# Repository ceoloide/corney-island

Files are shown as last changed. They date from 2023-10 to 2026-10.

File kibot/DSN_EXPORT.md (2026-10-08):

# KiCad DSN export repair

`export_dsn.py` repairs KiCad's native DSN using the source PCB. Run it in
KiCad's Python environment; the source board is never saved or modified.

```sh
python3 kibot/export_dsn.py -b board.kicad_pcb -o board.dsn
```

From the repository root with KiCad 9 Docker:

```sh
docker run --rm -v "$PWD:/board" -w /board --entrypoint python3 \
  ghcr.io/inti-cmnb/kicad9_auto:latest kibot/export_dsn.py \
  -b pcbs/corney_island_wireless.kicad_pcb -o /board/wireless.dsn
```

## Precision

KiCad serializes some coordinates with six significant digits, losing source
precision on large or rotated boards. The repair restores wire vertices, via
centers, polygonized board boundaries, footprint placements, local pin positions,
and identified circular NPTH centers. Source matching uses KiCad's native
rounding and source identity/net/layer where applicable. Ambiguous matches fail
instead of selecting a nearby point. Shared library images are split when
different source geometry has identical rounded serialization.

The repair preserves widths, rules, nets, layers, rotations, and declared DSN
resolution. It does not snap contacts to Freerouting's internal grid. Native
padstack shapes and arbitrary custom-pad geometry retain their exported values.
Arc tracks are unsupported; export fails rather than attempting to match them.
The implementation currently requires micrometer DSN exports and was tested
with KiCad 9.0.7. Output replacement is atomic, preserving existing output on
failure.

## NPTH clearance

The exporter preserves KiCad's native NPTH obstacle extents. It restores source
coordinate precision without removing the clearance already included in those
obstacles. The experimental `normalize_npth` utility remains in
`dsn_precision.py` with unit coverage, but is not invoked by the exporter.
There is no `--keep-native-npth` switch: preservation is the default behavior.

Freerouting's circular obstacle approximation and coordinate rounding remain
separate issues. Check imported routes with unfiltered KiCad DRC; precision
repair alone does not establish complete or correct autorouting.

## Build integration

`build.sh` applies the two-layer JLCPCB profile with `configure_jlcpcb.py`
before export and writes unfiltered pre-route and post-route DRC reports to
`reports/routing/`. Existing `.kicad_dru` files survive generation and are left
unchanged; the helper creates custom rules only if that file is absent.

`routing_status.py` rejects missing connections or DRC errors for the specific
board. Failed boards skip final fabrication exports, and the batch continues
with subsequent boards and prints a failure summary. Board-level failures do
not set a nonzero batch exit status; generation failures still do.

## Validation

```sh
python3 -m unittest discover -s kibot/tests -v
```

Thirteen tests cover coordinate restoration, ambiguous matches, descriptor
preservation, shared-image splitting, NPTH identity and layer matching,
oversized extents, implicit circle origins, rule-area rejection, and idempotence.
Integration checks on both saved keyboard boards and a ten-angle fixture verify
source-PCB preservation, unchanged rules/resolution/nets, and idempotence of the
precision repair. The batch regression checks that DRC and routing failures
do not prevent later boards from building and that custom rules are retained.
Freerouting import testing does not establish complete autorouting or replace
post-routing KiCad DRC.

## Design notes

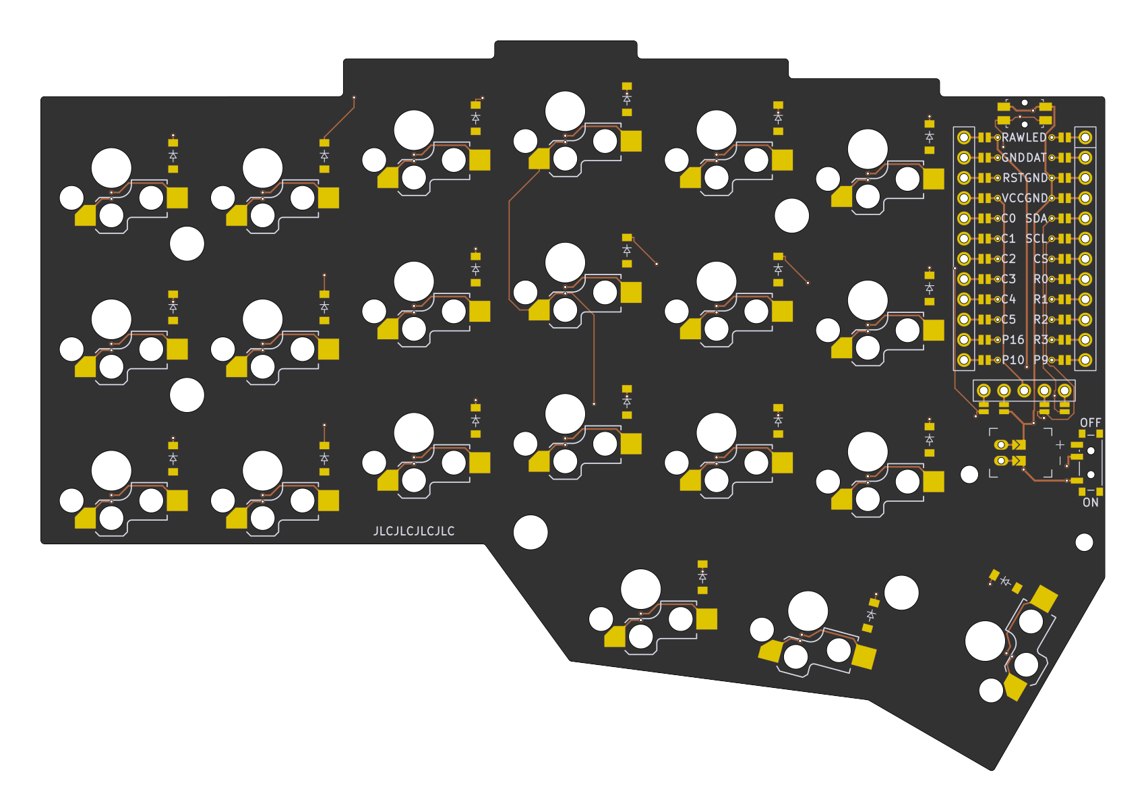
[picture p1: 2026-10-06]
images/corney_island_wireless_autorouted-top.png

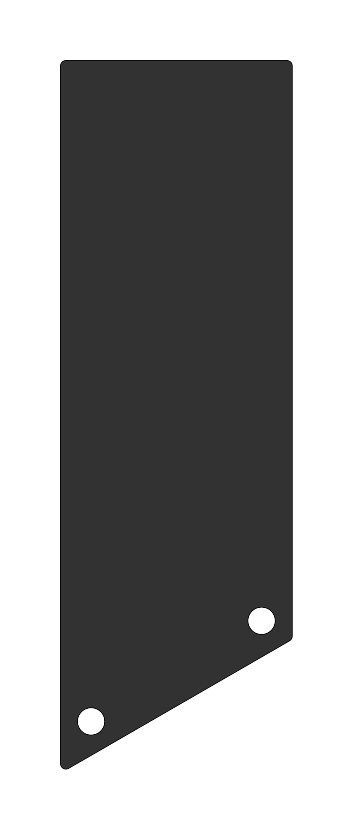
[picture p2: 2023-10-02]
images/controller_overlay-bottom.png

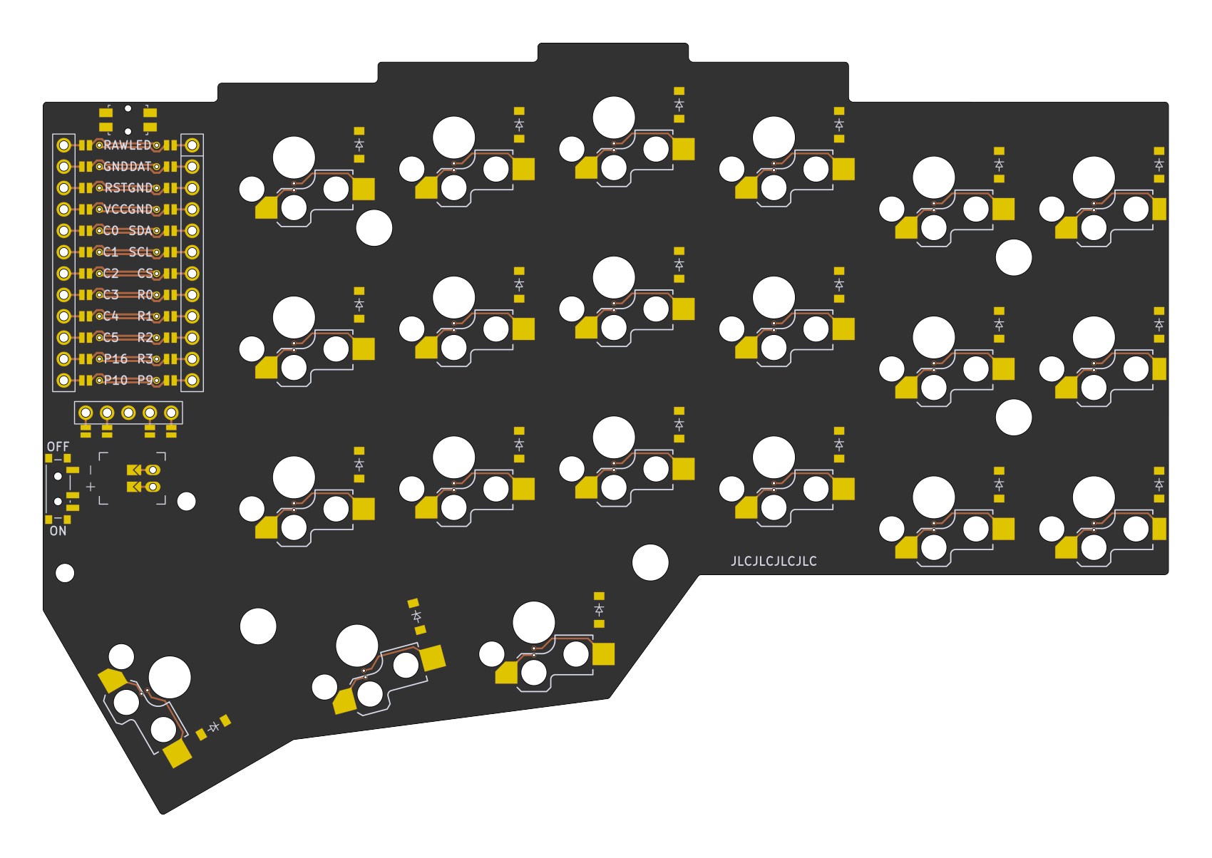
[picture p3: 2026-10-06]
images/corney_island_wireless-bottom.png

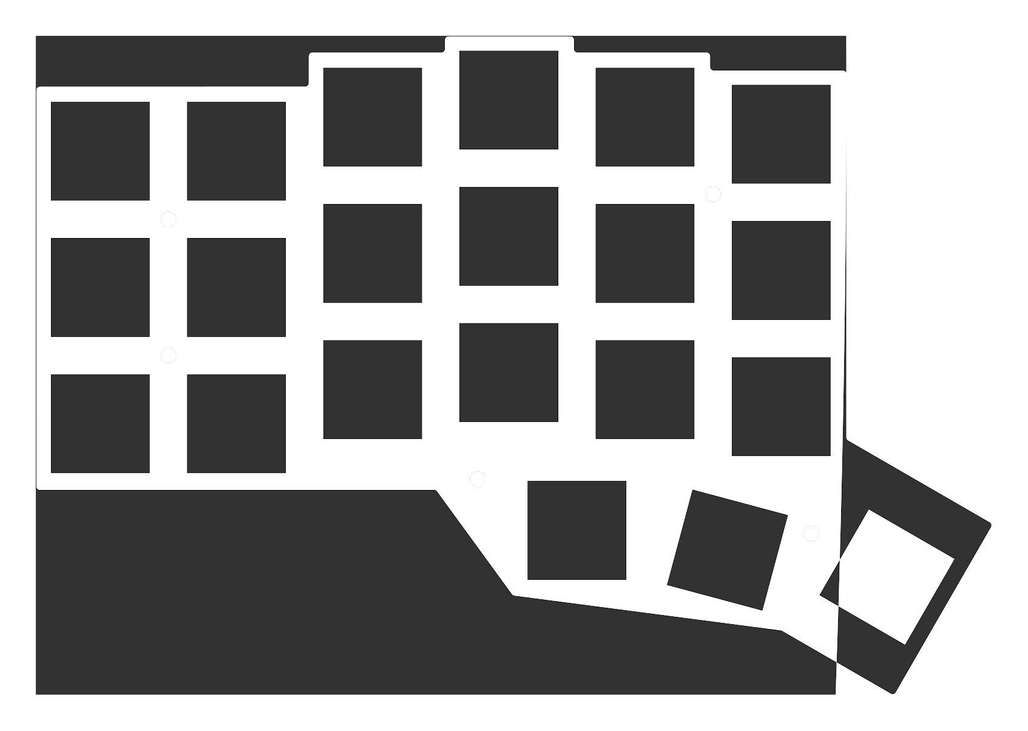
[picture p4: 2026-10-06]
images/frontplate-top.png

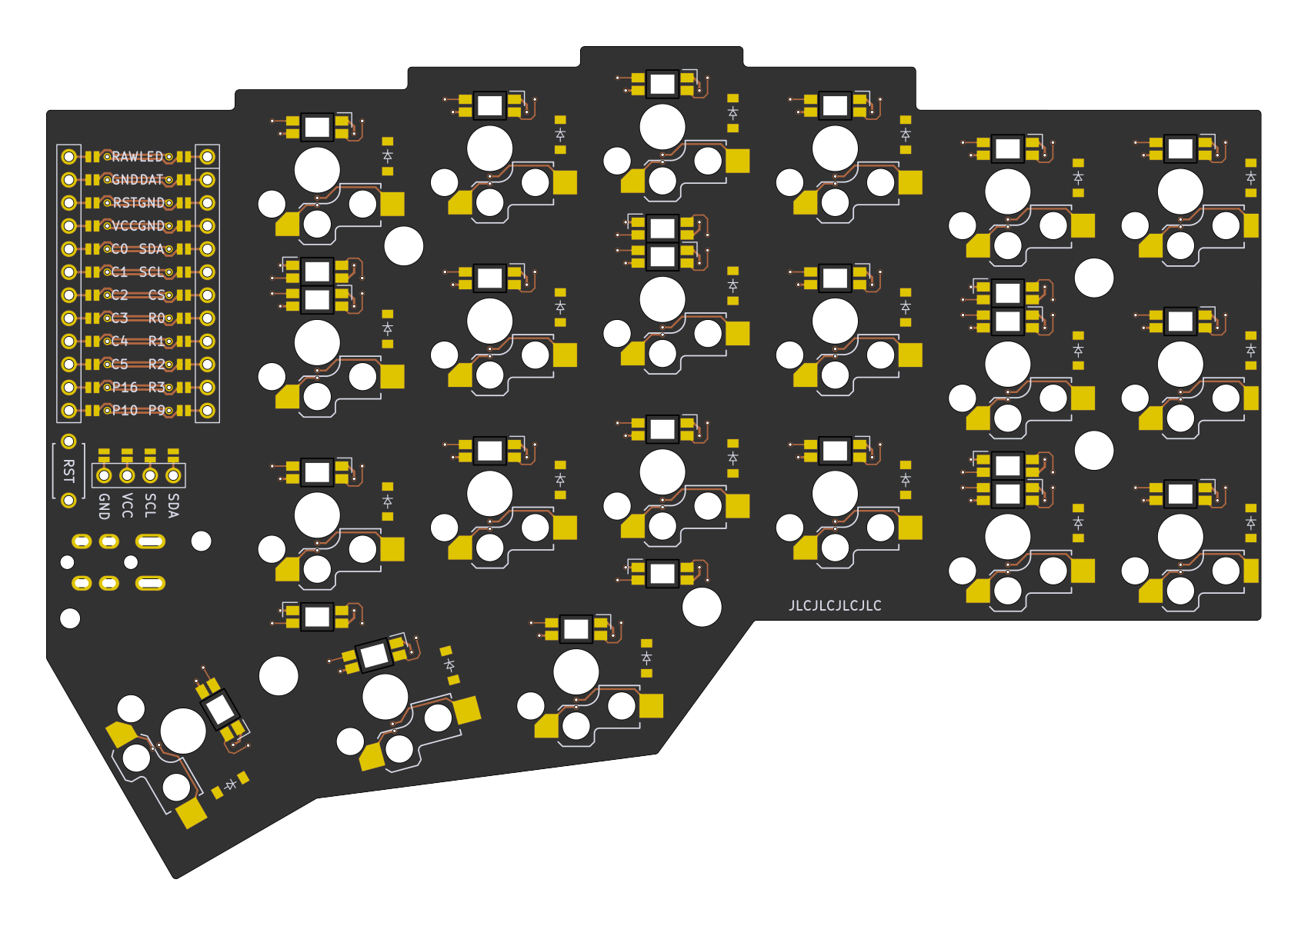
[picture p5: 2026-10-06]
images/corney_island-bottom.png

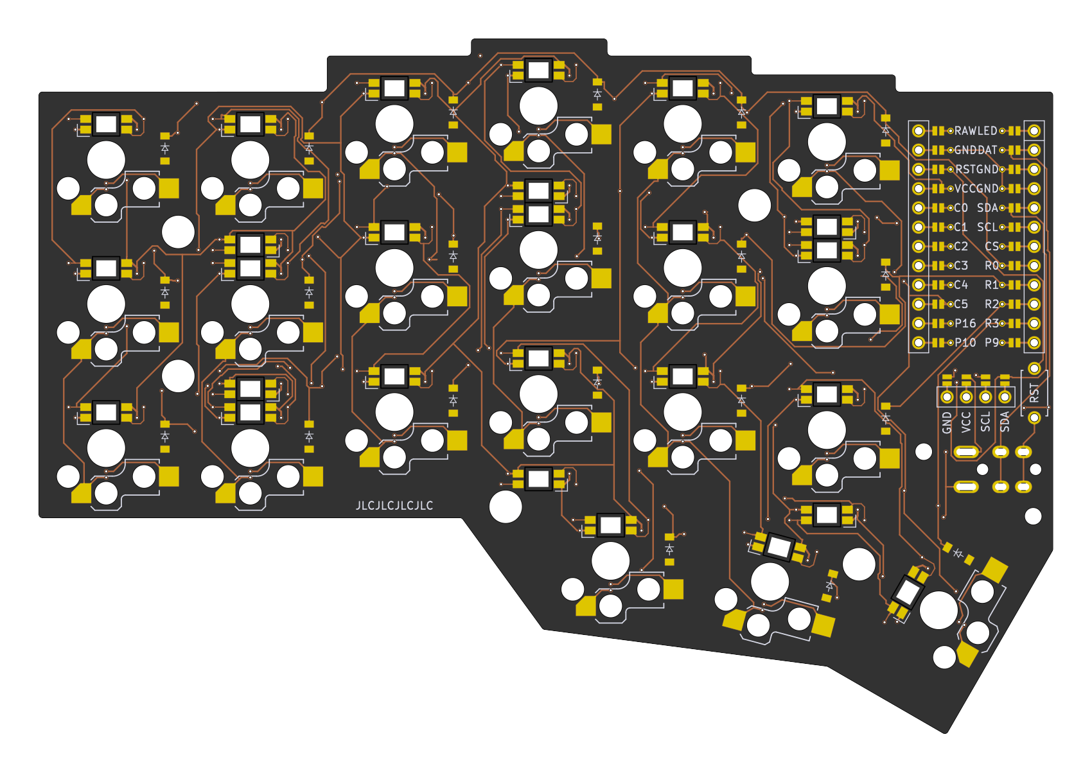
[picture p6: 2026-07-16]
images/corney_island_autorouted-top.png

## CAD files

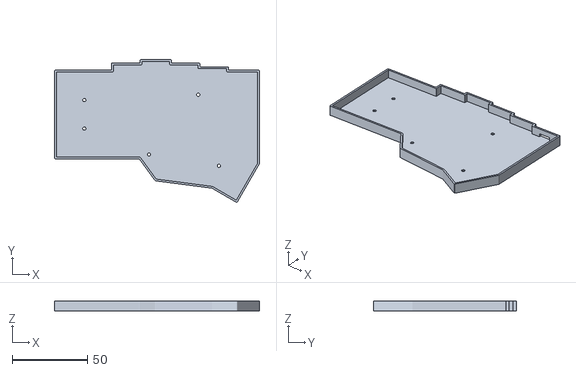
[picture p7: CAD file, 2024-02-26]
cases/corney_island_bottom_tray.stl
136.7 x 95.2 x 6.60

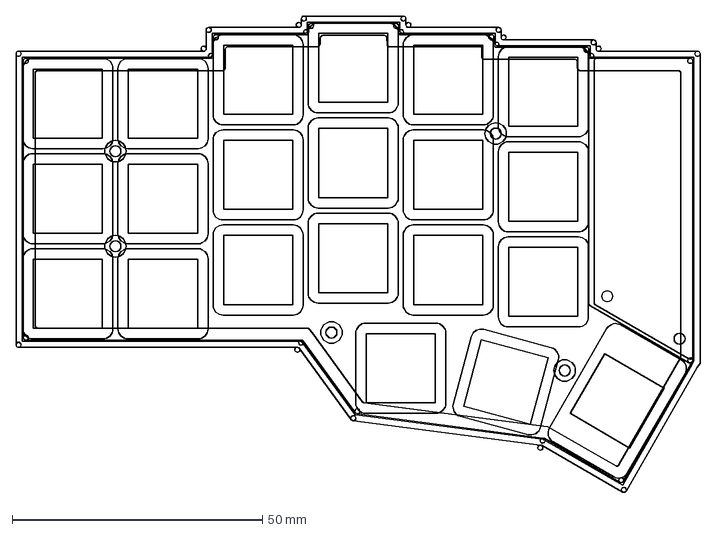
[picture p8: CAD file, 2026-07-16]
outlines/preview.dxf
136.7 x 95.2 mm

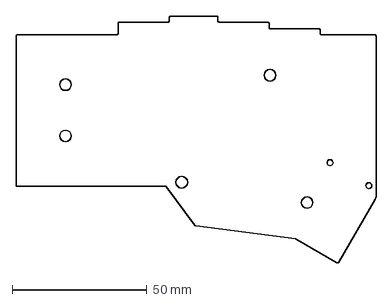
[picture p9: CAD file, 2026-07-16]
outlines/pcb.dxf
133.8 x 91.7 mm

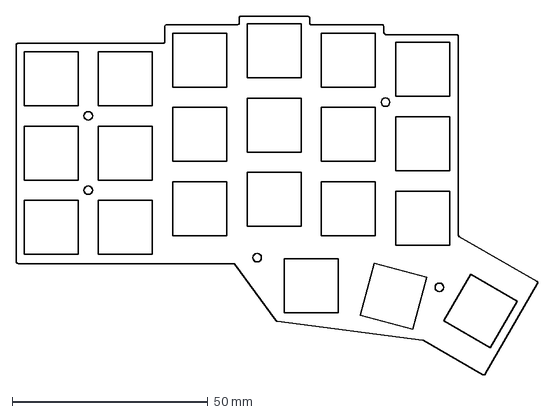
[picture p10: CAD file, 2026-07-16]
outlines/frontplate.dxf
133.3 x 91.7 mm

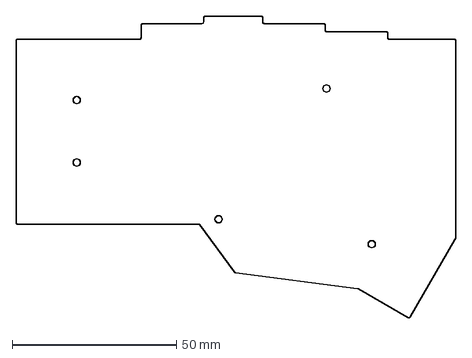
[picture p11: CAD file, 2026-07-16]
outlines/backplate.dxf
133.8 x 91.7 mm

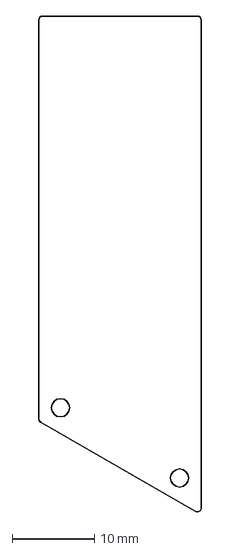
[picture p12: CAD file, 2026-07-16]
outlines/controller_overlay.dxf
19.7 x 60.1 mm

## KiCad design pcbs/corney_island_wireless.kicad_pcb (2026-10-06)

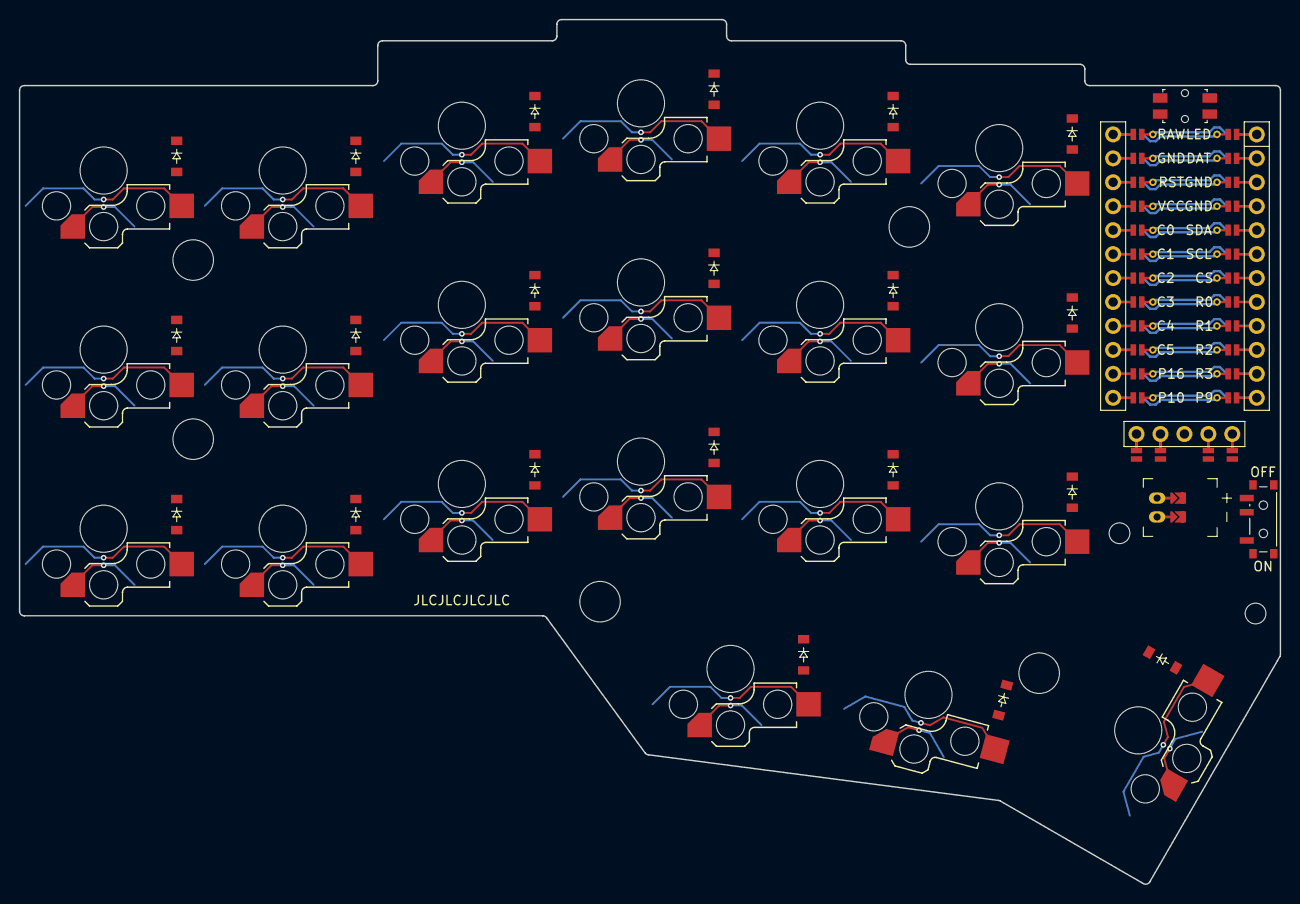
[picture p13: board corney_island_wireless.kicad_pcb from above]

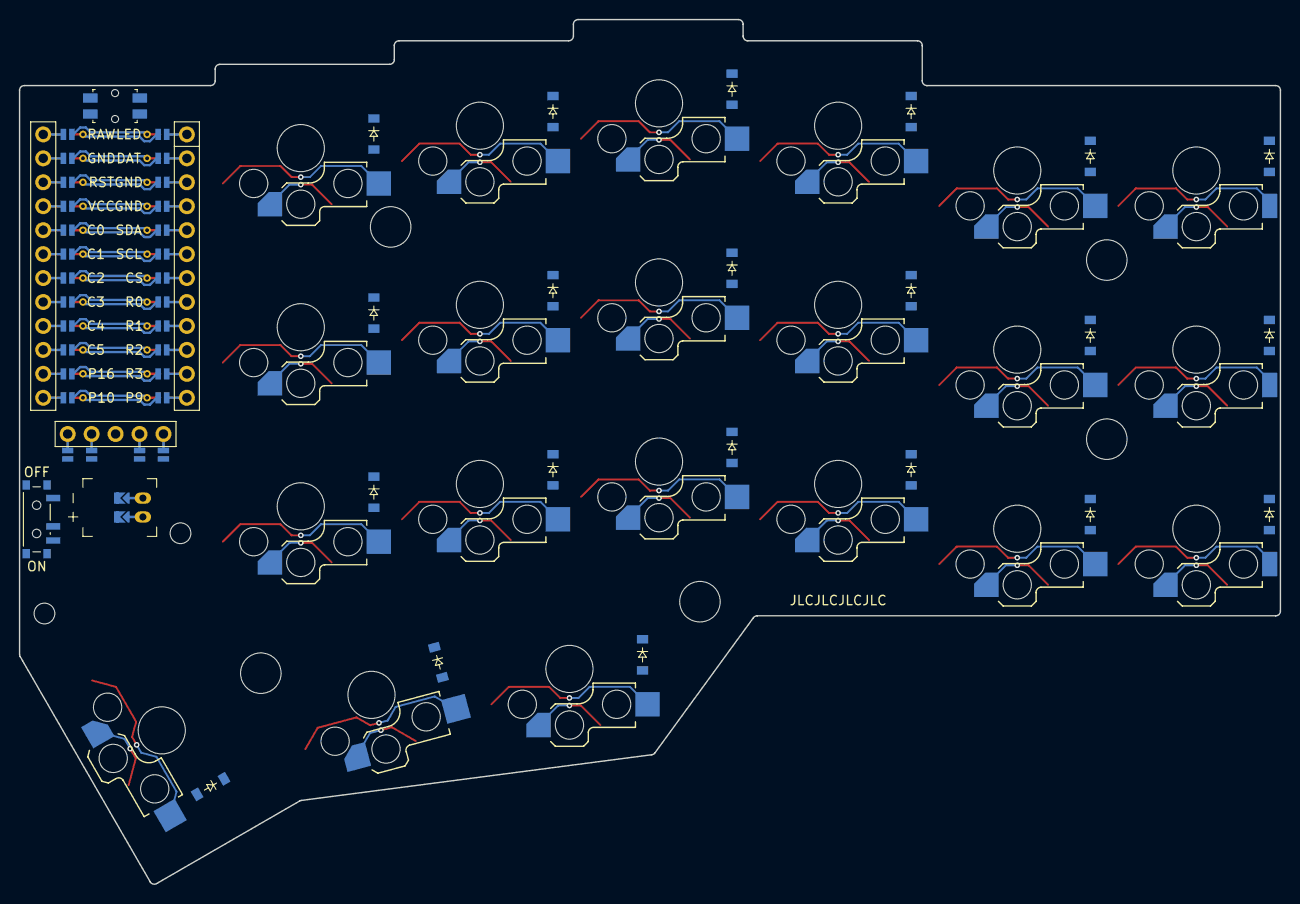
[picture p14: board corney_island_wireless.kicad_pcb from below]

Board: 2 copper layers, 133.8 x 91.7 mm, 75 parts (42 on the bottom side), 45 nets.

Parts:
D1, D2, D3, D4, D5, D6, D7, D8, D9, D10, D11, D12, D13, D14, D15, D16, D17, D18, D19, D20, D21, D22, D23, D24, D25, D26, D27, D28, D29, D30, D31, D32, D33, D34, D35, D36, D37, D38, D39, D40, D41, D42: diode_tht_sod123
DISP1: display_nice_view
JST1: battery_connector_jst_ph_2
MCU1: mcu_nice_nano
MH1, MH2, MH3, MH4, MH5, MH6, MH7: mounting_hole_npth
PWR1: power_switch_smd_side
RST1: reset_switch_smd_side
S1, S2, S3, S4, S5, S6, S7, S8, S9, S10, S11, S12, S13, S14, S15, S16, S17, S18, S19, S20, S21: switch_choc_v1_v2

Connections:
BAT_P: JST1.1, PWR1.1, PWR1.3
C0: MCU1.120, S1.1, S2.1, S3.1
C1: MCU1.119, S4.1, S5.1, S6.1
C2: MCU1.118, S7.1, S8.1, S9.1
C3: MCU1.117, S10.1, S11.1, S12.1, S19.1
C4: MCU1.116, S13.1, S14.1, S15.1, S20.1
C5: MCU1.115, S16.1, S17.1, S18.1, S21.1
CS: DISP1.10, DISP1.20, MCU1.107
DISP1_1: DISP1.1, DISP1.14, DISP1.27
DISP1_2: DISP1.2, DISP1.15, DISP1.26
DISP1_4: DISP1.4, DISP1.16, DISP1.25
DISP1_5: DISP1.5, DISP1.17, DISP1.24
GND: DISP1.11, DISP1.21, JST1.2, MCU1.103, MCU1.104, MCU1.123, RST1.1, RST1.3
JST1_1: JST1.11, JST1.21, JST1.31
JST1_2: JST1.12, JST1.22, JST1.32
R0: D3.1, D6.1, D9.1, D12.1, D15.1, D18.1, D24.1, D27.1, D30.1, D33.1, D36.1, D39.1, MCU1.108
R1: D2.1, D5.1, D8.1, D11.1, D14.1, D17.1, D23.1, D26.1, D29.1, D32.1, D35.1, D38.1, MCU1.109
R2: D1.1, D4.1, D7.1, D10.1, D13.1, D16.1, D22.1, D25.1, D28.1, D31.1, D34.1, D37.1, MCU1.110
R3: D19.1, D20.1, D21.1, D40.1, D41.1, D42.1, MCU1.111
RAW: MCU1.124, PWR1.2
RST: MCU1.122, RST1.2, RST1.4
SCL: DISP1.12, DISP1.22, MCU1.106
SDA: DISP1.13, DISP1.23, MCU1.105
VCC: DISP1.3, MCU1.121
far_home_B: D21.2, S21.2
index_bottom_B: D13.2, S13.2
index_home_B: D14.2, S14.2
index_top_B: D15.2, S15.2
inner_bottom_B: D16.2, S16.2
inner_home_B: D17.2, S17.2
inner_top_B: D18.2, S18.2
mid_home_B: D20.2, S20.2
middle_bottom_B: D10.2, S10.2
middle_home_B: D11.2, S11.2
middle_top_B: D12.2, S12.2
near_home_B: D19.2, S19.2
outer_bottom_B: D1.2, S1.2
outer_home_B: D2.2, S2.2
outer_top_B: D3.2, S3.2
pinky_bottom_B: D4.2, S4.2
pinky_home_B: D5.2, S5.2
pinky_top_B: D6.2, S6.2
ring_bottom_B: D7.2, S7.2
ring_home_B: D8.2, S8.2
ring_top_B: D9.2, S9.2

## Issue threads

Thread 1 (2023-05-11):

Reversible OLED fooprint

ceoloide, 2023-05-11:
As a user, I want to add an OLED screen footprint that can be mirrored or reversed.

finn-e, 2025-05-17:
https://github.com/chelming/chelming-kbd.pretty
There's one in here. It uses solder pads to choose which side is which. I don't think they're called solder pads, but my brain has forgotten the term for them at the moment. Check out the footprint and you'll see.
Also, thanks for all your hard work. You've created some great stuff.

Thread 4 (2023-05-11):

Combined and reversible SMD / THT diode footprint with vias

ceoloide, 2023-05-11:
As a user, I want to be able to add a diode footprint that can be reversed and can be set to be SMD, THT or a combination of those.

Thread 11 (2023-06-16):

Reversible reboot / boot switch

ceoloide, 2023-06-16:

Closed 2024-02-25.

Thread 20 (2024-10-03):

Error running 'ergogen'

monlovesmango, 2024-10-03:
hey,

repo looks great and is really helpful! however when I try running 'ergogen' on the config.yaml I get this error:

>Error: Field "pcbs.backplate.footprints.m2_screws.what" should be one of [alps, button, choc, chocmini, diode, jstph, jumper, mx, oled, omron, pad, promicro, rgb, rotary, scrollwheel, slider, trrs, via]!

ceoloide, 2024-10-03:
Sorry for the lack of a proper readme, and thank you for using my code!

The project leverages https://github.com/ceoloide/ergogen-footprints as a dependency for the footprints, so you need to make sure you have updated the git submodules as well before being able to run `ergogen` on this config:

```bash
git submodule update --init --recursive --remote
```

monlovesmango, 2024-10-03:
hmm that didn't work either, and neither did moving the .js files directly into the footprints folder. somehow ergogen isn't picking up added footprints, do you know if there is something I could be doing wrong that would cause this?

ceoloide, 2024-10-03:
Make sure you are pointing ergogen to the directory containing the `config.yaml` instead of the file itself, or it won't pick up the footprints.

In otherwords, call ergogen like this:

```bash
ergogen ergogen/
```

and not like this:

```bash
ergogen ergogen/config.yaml
```

monlovesmango, 2024-10-03:
that did it thank you! really appreciate the responsiveness too!

Closed 2024-10-03.

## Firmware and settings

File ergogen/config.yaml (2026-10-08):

meta:
  engine: 4.1.0
  name: corney-island
  version: 0.3 # Choc v2 POM switches variant
  ref: &kb_ref "Corney Island v0.3"
  author: ceoloide
  url: &kb_url https://github.com/ceoloide/corney-island
  # footprint: &switch_footprint "ceoloide/switch_mx"
  footprint: &switch_footprint "ceoloide/switch_choc_v1_v2"
  switch:
    # $extends: presets.mx
    # $extends: presets.choc_v1
    $extends: presets.choc_v2

presets:
  # These presets provide different layout options
  # Select a preset in the `units` section below
  # Note: The appropriate switch footprint will still need to be set in the `pcb` section
  mx:
    # Key and keycap measures
    kx: u # spacing between key centers (X-axis)
    ky: u # spacing between key centers (Y-axis)
    ks: 19 # horizontal space between columns (default: 19)
    kp: 19 # vertical padding between keys (deafult: 19)
    kcow: 14 # key cutout hole width (cherry: 14, choc: 13.8)
    kcoh: 14 # key cutout hole height (cherry: 14, choc: 13.8)
    keycw: 18 # keycap width (cherry: 18, choc: 17.5)
    keych: 18 # keycap height (cherry: 18, choc: 16.5)
    led_pos_x: 0 # Led X position relative to the switch center
    led_pos_y: -4.75 # Led Y position relative to the switch center
    led_rotation: 180 # Led rotation
    vertical_underglow_shift: -0.5 kp # How much to shift underglow leds tied to keys
    vertical_diode_shift: 1.325 # How much to shift to avoid overlap
    horizontal_diode_shift: 7.4
    diode_rotation: 0 # Diode rotation
    switch_rotation: 0 # Hotswap north, led south
  choc_v1:
    # Key and keycap measures
    kx: cx # spacing between key centers (X-axis)
    ky: cy # spacing between key centers (Y-axis)
    ks: 18.5 # horizontal space between columns (default: 19)
    kp: 17.5 # vertical padding between keys (deafult: 19)
    kcow: 13.8 # key cutout hole width (cherry, choc v2: 14, choc v1: 13.8)
    kcoh: 13.8 # key cutout hole height (cherry, choc v2: 14, choc v1: 13.8)
    keycw: 17.5 # keycap width (cherry: 18, choc: 17.5)
    keych: 16.5 # keycap height (cherry: 18, choc: 16.5)
    led_pos_x: 0 # Led X position relative to the switch center
    led_pos_y: 4.7 # Led Y position relative to the switch center
    led_rotation: 0 # Led rotation
    vertical_underglow_shift: -kp + 7.8  # How much to shift underglow leds tied to keys
    vertical_diode_shift: 1.5 # How much to shift to avoid overlap
    horizontal_diode_shift: -0.5 kcow - 0.85
    diode_rotation: -180 # Diode rotation
    switch_rotation: 180 # Hotswap south, led north
  choc_v2:
    # Key and keycap measures
    $extends: presets.choc_v1
    kx: u # spacing between key centers (X-axis)
    ky: u # spacing between key centers (Y-axis)
    ks: 19 # horizontal space between columns (default: 19)
    kp: 19 # vertical padding between keys (deafult: 19)
    keycw: 18 # keycap width (cherry: 18, choc: 17.5)
    keych: 18 # keycap height (cherry: 18, choc: 16.5)

units:
  # The following statements will make the content of the preset
  # available in the units context
  $extends: meta.switch

  hand_rotation: 0

  # Physical measures
  screw_radius: 1.1 # M2 screws
  screw_diameter: screw_radius * 2
  screw_head_radius: 2.05
  screw_head_diameter: screw_head_radius * 2
  spacer_radius: 2.15 # M2 standoffs
  spacer_diameter: spacer_radius * 2
  fillet_radius: 0.5
  pwr_trace_width: 0.25
  gnd_trace_width: 0.25
  signal_trace_width: 0.15
  via_size: 0.56 # JLCPCB min 0.56 | KiCad default 0.8
  via_drill: 0.3 # JLCPCB min 0.3 | KiCad default 0.4

  # Case variables
  case_wall_thickness: 1.2
  pcb_to_case_wall_tolerance: 0.25
  bottom_plate_thickness: 1.0
  top_plate_thickness: 1.6
  internal_distance_between_plates: 4

  # Thumb splay
  splay_thumb_middle: 15
  splay_thumb_far: 15
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

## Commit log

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2023-05-04 Add ergogen output to GitHub
    [backplate.dxf, controller_overlay.dxf, corney_island.kicad_pcb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]
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2023-05-05 Fix OLED pad position
    [corney_island.kicad_pcb]
2023-05-05 Add reset switch
    [corney_island.kicad_pcb]
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2023-05-05 Remove vias from the PCB
    [corney_island.kicad_pcb]
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2023-05-10 Switch from sod-123w to diode to fix GH workflow
    [config.yaml]
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2023-05-11 Add additional outputs: images, routed PCB, gerber
    [corney_island.kicad_pcb, corney_island_routed.kicad_pcb]
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2023-05-11 Fix diode rotation (typo)
    [config.yaml]
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2023-05-11 Update outputs with additional plate files
    [backplate.kicad_pcb, controller_overlay.kicad_pcb, corney_island.kicad_pcb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]
2023-05-18 Add meta and preset to config.yaml
    [backplate.kicad_pcb, controller_overlay.kicad_pcb, corney_island.kicad_pcb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]
2023-05-20 Fix diode position
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2023-06-04 Add LED cutouts
    [corney_island.kicad_pcb, corney_island_routed.kicad_pcb, pcb.dxf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]
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2023-06-05 Fix key positions to exactly match the corne
    [backplate.dxf, backplate.kicad_pcb, controller_overlay.dxf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]
2023-06-05 Fix screw spacer holes to match the corne
    [corney_island.kicad_pcb, corney_island_routed.kicad_pcb, pcb.dxf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]
2023-06-05 Fix screw mounting holes positions
    [config.yaml]
2023-06-05 Fix MCU cover mounting holes position
    [backplate.dxf, backplate.kicad_pcb, controller_overlay.dxf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]
2023-06-06 Fix component positions to match the corne
    [corney_island.kicad_pcb, corney_island_routed.kicad_pcb]
2023-06-06 Update nets and diode positions
    [corney_island.kicad_pcb, corney_island_routed.kicad_pcb]
2023-06-06 Add per-key reversible LEDs
    [corney_island.kicad_pcb, corney_island_routed.kicad_pcb, pcb.dxf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]
2023-06-06 Switch to reversible TRRS jack
    [corney_island.kicad_pcb, corney_island_routed.kicad_pcb]
2023-06-06 Add LED and diode rotation, diode shift
    [corney_island.kicad_pcb, corney_island_routed.kicad_pcb]
2023-06-06 Fix missing diode rotation
    [corney_island.kicad_pcb, corney_island_routed.kicad_pcb]
2023-06-07 Fix LED silk screen
2023-06-08 Update generated files
    [corney_island.kicad_pcb, corney_island_routed.kicad_pcb]
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2023-06-11 Revert to 128x32 F-only oled
    [config.yaml]
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2023-06-13 Update MCU pinouts
    [corney_island.kicad_pcb, corney_island_routed.kicad_pcb]
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2023-06-14 Add the option to flip the footprint
2023-06-14 Add underglow LEDs
    [corney_island.kicad_pcb, corney_island_routed.kicad_pcb]
2023-06-14 Fix pin order
2023-06-14 Update LED options and rotation
    [corney_island.kicad_pcb, corney_island_routed.kicad_pcb]
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2023-06-15 Fix wrong preset reference
    [config.yaml]
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2023-06-16 Fix screw position and simplify shift values
    [config.yaml]
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2023-07-24 Fix inner underglow LED position
    [backplate.dxf, backplate.kicad_pcb, corney_island.kicad_pcb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]
2023-07-24 Overhaul outlines making use of intersect
    [backplate.dxf, backplate.kicad_pcb, controller_overlay.dxf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]
2023-07-24 Change to relative measures for helper points
    [backplate.dxf, backplate.kicad_pcb, corney_island.kicad_pcb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]
2023-07-24 Add missing parametric measures
    [backplate.dxf, backplate.kicad_pcb, corney_island.kicad_pcb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]
2023-07-24 Fix keycap and preview outlines
    [preview.dxf]
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2023-08-15 Refresh generated files.
    [backplate.kicad_pcb, controller_overlay.kicad_pcb, corney_island.kicad_pcb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]
2023-08-27 Fix missing led net reference
    [config.yaml]
2023-08-27 Fix LED net order
    [config.yaml]
2023-09-11 Fix duplicate thru-hole pads in reversible config
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2023-09-26 Split diode position on F and B layers
    [corney_island.kicad_pcb, corney_island_routed.kicad_pcb]
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2023-09-30 Fix list of boardcs in GitHub Action
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2023-10-02 Switch to infused-kim nice-nano footprint
    [corney_island.kicad_pcb, corney_island_routed.kicad_pcb]
2023-10-03 Fix per-key LED rotation on MX switches
    [config.yaml]
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2023-10-11 Fix reset switch silk screen text size
    [config.yaml]
2023-10-11 Fix LED orientation, traces, keepout
2023-10-11 Update traces with correct clearance values
    [config.yaml]
2023-10-11 Update artifacts with latest unrouted build
    [corney_island.kicad_pcb]
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2023-10-12 Update artifacts with latest config + manual trace
    [corney_island.kicad_pcb, corney_island_manually_routed.kicad_pcb]
2023-10-12 Fix usage of old data net name for TRRS
    [corney_island.kicad_pcb]
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2023-10-12 Add JLCPCB production number text
    [corney_island.kicad_pcb, corney_island_manually_routed.kicad_pcb, test.kicad_pcb]
2023-10-13 Fix pin 1 and 2 of the TRRS footprint
    [corney_island_manually_routed.kicad_pcb]
2023-10-13 Add board name and version
    [corney_island_manually_routed.kicad_pcb]
2023-10-15 Add nets and defaults
    [corney_island.kicad_pcb]
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2023-10-15 Remove unused test PCB
    [test.kicad_pcb]
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2023-10-16 Update assets
    [corney_island.kicad_pcb, corney_island_routed.kicad_pcb]
2023-10-16 Switch routed board suffix to `_autorouted`
    [corney_island_autorouted.kicad_pcb]
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2023-10-17 Add expected errors to KiBot filters
2023-10-17 Update clearance and via rules for PWR/GND
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2023-10-17 Add partially routed PCB output
    [corney_island_mx_partially_routed.kicad_pcb]
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2023-10-19 Switch to kicad_default clearance to avoid error
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2023-10-23 Replace screw holes with spacer holes
    [config.yaml]
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2023-10-24 Fix wrong DIN / DOUT reference for underglow
    [config.yaml]
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2023-10-30 Remove partially routed board
    [corney_island_mx_partially_routed.kicad_pcb]
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2023-11-05 Invert diode X position for choc switches
    [config.yaml]
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2023-11-22 Fix on/off switch position for clearance violation
    [config.yaml]
2023-11-22 Update wireless assets
    [corney_island_wireless.kicad_pcb, corney_island_wireless_autorouted.kicad_pcb]
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2023-11-26 Fix footprint reference text
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2023-11-30 Add wireless autoroute assets
    [corney_island_wireless_autorouted.kicad_pcb]
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2024-01-14 Fix pin polarity
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2024-01-15 Replace edge cut holes with footprint
    [config.yaml]
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2024-01-17 Make use of the correct power button
    [config.yaml]
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2024-01-18 Add option to invert switch behavior
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2024-01-18 Fix position and size of stabilizer hole for choc v2
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2024-01-19 Invert silkscreen labels so they are read correctly on the soldering side
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2024-02-26 Add 3D printed bottom case
    [corney_island_bottom_tray.stl, preview.dxf]
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2024-03-03 Add missing output for manually routed board
2024-03-30 Update TRRS footprint pinout and module
    [backplate.kicad_pcb, controller_overlay.kicad_pcb, corney_island.kicad_pcb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]
2024-04-01 Switch to HTTPS for footprints submodule, to make it work with Codespaces
2024-04-01 Update build scripts to make use of KiCad Auto ki8 image (KiCad 8)
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2024-04-01 Update GitHub Actions to make use of KiCad Auto ki8 (KiCad 8)
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2024-04-05 Update footprints library and artifacts
    [corney_island.kicad_pcb, corney_island_autorouted.kicad_pcb, corney_island_wireless.kicad_pcb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]
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2024-04-11 Slightly move the reset switch to avoid overlap with new display footprint
    [config.yaml]
2024-04-11 Switch to KiCad 8 PCB template and require Ergogen v4.1.0
    [backplate.kicad_pcb, controller_overlay.kicad_pcb, corney_island.kicad_pcb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]
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2024-11-14 Update build pipeline to use Freerouting 2.0.1
    [backplate.dxf, backplate.kicad_pcb, controller_overlay.dxf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]
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2025-09-17 Fix output paths for images and gerbers
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2026-07-16 build: regenerate outlines and PCBs using Ergogen v4.3.0
    [backplate.dxf, backplate.kicad_pcb, controller_overlay.dxf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]
2026-07-16 build: generate PCB layouts, routing, gerbers, and preview images
    [backplate.kicad_pcb, controller_overlay.kicad_pcb, corney_island_autorouted.kicad_pcb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]
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2026-07-16 Revert "chore: update build script to use KiCad 9 and Ergogen snapshot"
    This reverts commit 3f451795d5d4e778867fe3b92f1dfd83fe9221a0.
2026-09-06 chore: update workflow and scripts to KiCad 9, Ergogen snapshot, and k9_snapshot_2.4.1
2026-09-06 build: regenerate outlines and PCBs with Ergogen snapshot
    [backplate.kicad_pcb, controller_overlay.kicad_pcb, corney_island.kicad_pcb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]
2026-10-06 chore: update Freerouting CLI parameters and GitHub Actions workflow
    - Update Freerouting max_passes parameter to --router.autorouter.max_passes
    - Update user data path to --user_data_path=./freerouting
    - Fix log4j2 configuration URI format
    - Ignore generated freerouting.json
    - Update GitHub Actions workflow: pin ubuntu-24.04, upgrade actions to v7 (Node 24), and remove deprecated docker-cache step
2026-10-06 build: regenerate PCBs, images, and gerbers
    [backplate.kicad_pcb, controller_overlay.kicad_pcb, corney_island.kicad_pcb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]
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2026-10-07 fix(autoroute): dynamically adapt rules board name and align max_passes to 25
2026-10-07 fix(rules): update SMD clearance to 0.200 mm to align with design rules
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2026-10-08 fix(footprints): use rectangular battery connector jumpers
    [config.yaml]
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2026-10-20 fix(build): restore NPTH normalization and regenerate boards
    Normalize source-proven NPTH export obstacles by default, with a native-export opt-out. Pin and verify Freerouting 2.5.1-SNAPSHOT at upstream head 1be66ad and use KiCad 9 for generation, import, and DRC. Make CI run the same build and withhold stale or failing fabrication outputs.
    Regenerate the keyboard boards and plates from YAML, including the configured rectangular JST jumpers. Retain routed review boards and unfiltered validation evidence: wireless has one open C4 connection; wired has two open VCC connections. Routing introduces no new KiCad DRC errors. Existing LED clearance and frontplate outline findings remain documented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
2026-10-21 Refresh generated Corney Island boards and KiCad projects
    Regenerate with KiCad 9.0.7+1 and the Freerouting fixes at 48c969dd, using
    neckdown and fanout disabled, one worker, and optimization enabled. The fixed
    JAR was mounted over the pinned image for this local build.
    Both boards have zero missing connections after SES import. Wireless has no
    DRC errors; wired retains the 16 source copper-edge errors. The frontplate
    still fails its outline check, so failed-board fabrication exports are skipped.
    Regenerate wireless fabrication outputs after the unfiltered KiCad DRC passes,
    bypassing KiBot's subsequent HTML-report parsing failure. Include the generated
    project settings with the boards, rep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
2026-10-23 Update LED footprint clearance and refresh generated boards
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
